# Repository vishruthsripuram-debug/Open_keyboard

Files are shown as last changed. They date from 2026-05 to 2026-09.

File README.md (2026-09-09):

# Nano pad
A 4 key macro pad that you can program actions to.
Screenshot 2026-05-01 at 12 41 59 pm

## Design
My inspiration for this macro pad was the printed pad by prota design but i wanted to make something smaller and cheaper than both of their offering the printed pad and glyff. The printed pad being $68 seemed quite unreasonable to me seeing as it was only a screen a few key swicthes and a microcontroller.

I wanted the project to be simple and easily accessible and customisable by many people so all of the PCB design files are included in the rep for download and printing from a pcb service. The case is 3d printable in any colour you like and customisable to include a knob or other features as step and other cad files are included. The model has also been published on makerworld for the ease of use with Bambulab printers. The whole idea is to hace a simple good looking macro pad that anyone can own for under $15 USD, for 25 USD you can own 5 macro pads.

## BOM

## Bill of Materials — Macro Pad

| Item # | Designator | Qty | Manufacturer | Mfg Part # | Description / Value | Package/Footprint | Type | Notes |
|---|---|---|---|---|---|---|---|---|
| 1 | SW1, SW2, SW3, SW4 | 4 | Cherry (preferred) | MX1A-G1NW | MX Brown, tactile, PCB mount, 5-pin | SW_Cherry_MX_1.00u_PCB | THT | If out of stock, substitute OK: any 5-pin PCB-mount MX-compatible Brown tactile switch (e.g. Gateron KS-3 Brown, Kailh Box/MX Brown, Outemu Brown) — all fit this footprint |
| 2 | U1 | 1 | DFRobot | DFR0648 | Fermion 0.91" 128x32 SSD1306 OLED, I2C, top-mounted pin header (OLED-B) | Module, pin header, THT | THT | Pins are on the short top edge, NOT the long side — confirm this exact pinout before substituting |
| 3 | U2 | 1 | Seeed Studio | 101991470 | XIAO ESP32-C6 module (Tape and Reel, SMD variant) | SMD castellated module | SMD | — |

## Software
software

## Collaboration
In collaboration with PCBWay


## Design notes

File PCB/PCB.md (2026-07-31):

All of the PCB files are located in this folder

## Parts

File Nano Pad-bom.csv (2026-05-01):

Name | Purpose | Quantity | Total Cost (USD) | Link | Distributor
seeed studio esp32 c6 | micrcontroller | 1 | 5.00 | https://www.digikey.com/en/products/detail/seeed-technology-co-ltd/113991254/24613066 | digikey
Key switches | for the macropad buttons | 1 | 2.00 | https://keychron.com.au/products/cherry-switch-set | keychron/aliexpress
Screen | to display features | 1 | 2.50 | https://aliexpress.com | aliexpress
PCB | To connect all components | 1 | 1.00 | https://cart.jlcpcb.com/shopcart/cart | JLC PCB

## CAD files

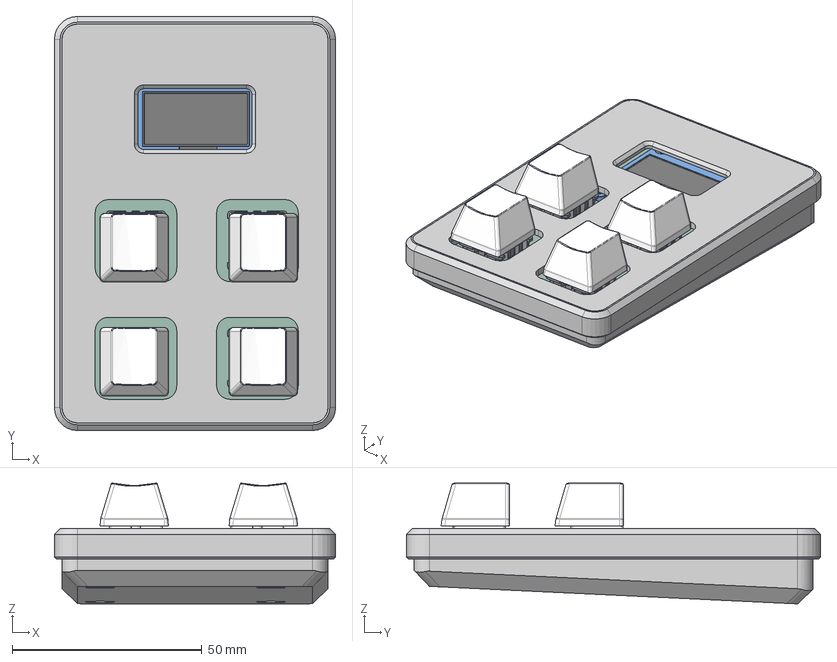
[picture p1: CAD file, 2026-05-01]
3D models/Macro pad.step
74.0 x 109.0 x 31.8 mm
Base
Adafruit_SSD1306
Macro pad_PCB
Bottom x 4
Pulsador x 4
Top x 4
Pieza5^Cherry MX x 4
Pin1 x 4
Pin2 x 4
Led 3mm_trans x 4
Lid
BOSS-EXTRUDE14_8_
BOSS-EXTRUDE7_4_
BOSS-EXTRUDE7_3_
BOSS-EXTRUDE14_4_
BOSS-EXTRUDE14_2_
BOSS-EXTRUDE14_11_
BOSS-EXTRUDE7_7_
BOSS-EXTRUDE14_9_
BOSS-EXTRUDE14_3_
BOSS-EXTRUDE14_7_
MIRROR2
BOSS-EXTRUDE14_5_
BOSS-EXTRUDE14_12_
BOSS-EXTRUDE7_8_
BOSS-EXTRUDE7_1_
BOSS-EXTRUDE14_10_
BOSS-EXTRUDE7_9_
BOSS-EXTRUDE14_6_
BOSS-EXTRUDE14_1_
BOSS-EXTRUDE7_6_
BOSS-EXTRUDE7_2_
CUT-EXTRUDE5
BOSS-EXTRUDE7_5_
U.FL Connector v1
Button (1) x 2
Shield
MX Öá±ê×¼¼üÃ±_ _¨¹_¡À__¡§1__¨¤ x 4

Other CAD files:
3D models/Macro pad.3mf
3D models/Macro pad.f3z

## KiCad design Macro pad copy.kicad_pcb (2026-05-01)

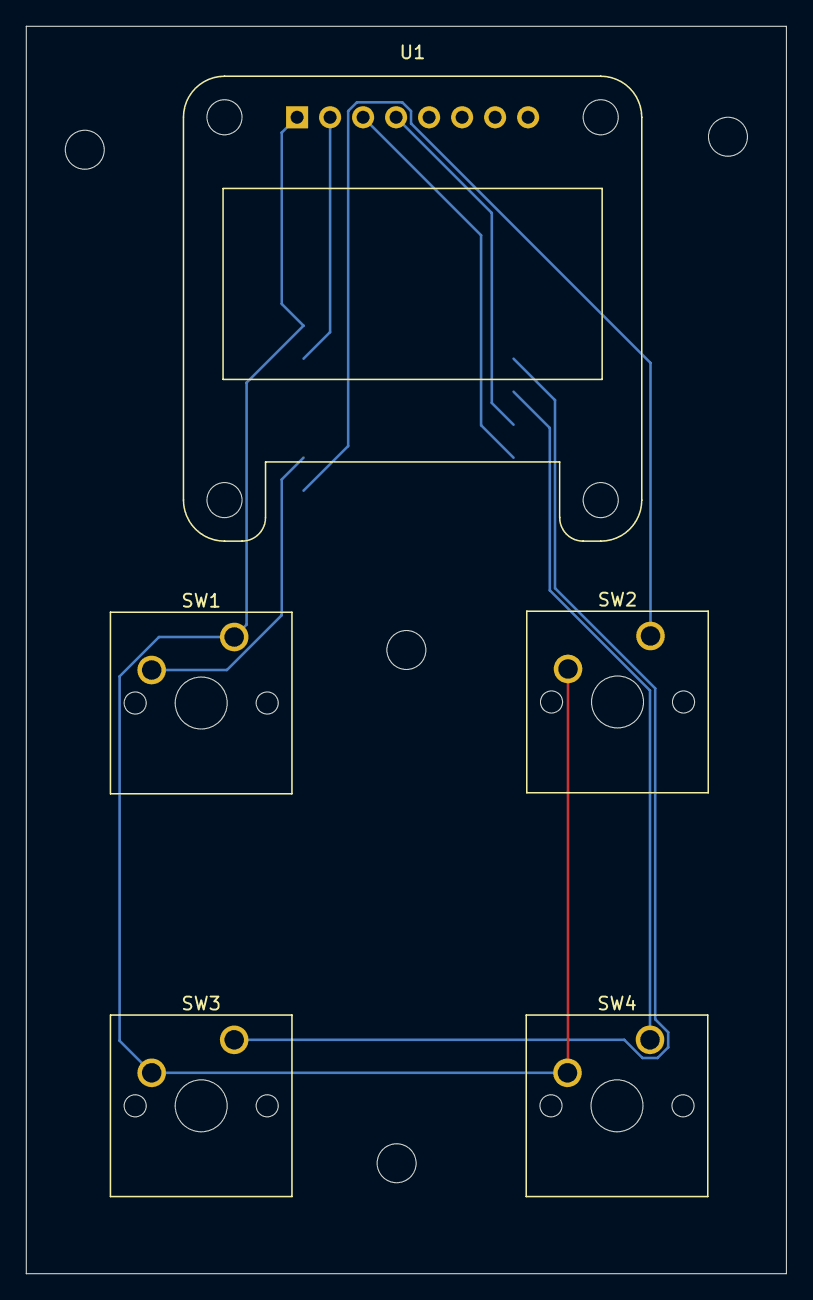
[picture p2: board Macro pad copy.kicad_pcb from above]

Board: 2 copper layers, 58.5 x 96.0 mm, 6 parts (1 on the bottom side), 8 nets.

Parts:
SW1, SW2, SW3, SW4: SW_Push; SW_Cherry_MX_1.00u_PCB
U1: ER_OLEDM0.91_1x-I2C; Adafruit_SSD1306
U2: MOUDLE-SEEEDUINO-XIAO; XIAO-ESP32-C6-SMD

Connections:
GND: SW1.1, SW2.2, SW3.2, SW4.2, U1.1 (GND), U2.13 (GND)
unnamed: U1.3 (SCL), U2.6 (PA9_A5_D5_SCL)
unnamed: U1.4 (SDA), U2.5 (PA8_A4_D4_SDA)
unnamed: U1.2 (VCC), U2.12 (3V3)
unnamed: SW1.2, U2.9 (PA7_A8_D8_SCK)
unnamed: SW3.1, U2.3 (PA10_A2_D2)
unnamed: SW4.1, U2.4 (PA11_A3_D3)
unnamed: SW2.1, U2.8 (PB09_A7_D7_RX)

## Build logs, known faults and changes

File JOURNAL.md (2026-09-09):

# 5/1/2026 - Designing PCB

**Time spent:** 5.5h

PCB Design



Schematic

I first started with the schematic, for the schematic i decided to follow the Hackpad guide for the switches and the microcontroller but i decided to add my own twist which was the screen. The screen is an adafruit oled display with screw mounting holes for mounting onto the PCB. The schematic also included the seeeduino board used in the hackpad guide.

I had to do the schematic twice because for the first time i didnt properly connect the parts together in the schema so in the PCB editor when i was routing the routes weren't connecting.

For the schematic my main concern was with the Tracing. finding the most optimal paths for the lines was incredibly difficult and arranging the traces. The traces were particularly hard to arrange with the ground line but i figured out that i could instead use the same extended ground line essentially piggy backing off of the other ground pins.



*The wiring of the schematic was a bit messy because of the layout i used*

PCB editor

Within the PCB editor is where i designed the main PCB, it took me a while to figure out that i had to assign footprints to the components in the schematic editor. I then placed all of the components in a desirable layout for the macro pad making it simple and good looking fr the macropad. I realised the gap was quite significant when designing in fusion however I was able to fix this after the fact.

The routing was the most significantly difficult part in my opinion it took me multiple attempts and a bunch of tries after deleting multiple routes because the others didn't fit and then, i finally found a layout that would work, but in the DRC it said that my components weren't connected so i check back and realised all my routes were in the top layer of my PCB and not connecting to the microcontroller on the bottom layer, so i had to undo everything and restart from the bottom layer. I realised i could interconnect the ground pins to simplify the layout and reduce the overall wires going to the microcontroller.



After a while of trial and error i eventually figured it out and was able to properly route everything and the DRC showed a fully working PCB, i also learnt about the layers which instructed me to build the pcb frame on the edge cuts layer.

---

# 5/1/2026 - CAD design

**Time spent:** 3.5h

I designed the PCB case in Fusion 360

My inspiration for this macro pad was the printed pad by Prota design but i wanted to make something smaller and cheaper than both of their offering the printed pad and glyff.

Step 1

I first exported the step file of my PC into fusion by exporting out of KIcad, here i encountered some errors explained in the previous journal entry where my routing want correct and the DRC wasnt approving my project to be exported due to those errors. Eventually i figured it out and exported it as a step file into fusion 360 where i opened a hybrid design file.

Chellenge
The main challenge with the cad was making it look nice. The Macropad had to be simple and look nice, which was a key requirement. When i designed it it had smooth chamfers and fillets to reflect the design language i was aiming for. The black design refelcts the prota pad well. Further when designing i had to allow ample clearance between the keycaps for them to glide smoothly into the macropad when clicking. 

Finding the correct Cad files for the 



After importing everything into fusion i started the creation of my case for the macro pad PCB. So far i have the PCB laid in the frame with switches laid on top. The switches are cherry mx red switches which provide a satisfying clicking experience had smooth travel. I placed the switches onto the PCB and they fit perfectly.

Whats left

I still have to make a cutout for the microcontroller mounted on the bottom and another cutout for the USB-C cord which provides power and signal to the macro pad.

I also have to design the top shell of the case similar to the Prota design case.

---

# 5/1/2026 - More fusion - Designing lid and adding keycaps

**Time spent:** 3h

In the previous journal entry i said that i would complete the Lid and add the USB charging port and thats what i did.

I designed the lid simply by just creating a sketch on top of the base and creating a 2mm offset for a sturdy but light feel. The holes for the keyswitches have decent clearance for the kycaps to go beneath the top layer for full travel. Cherry mx switches can detect travel amount so i plan to use this in firmware.



---

# 5/1/2026 - I developed the code and editing software for the macropad

**Time spent:** 4.5h

I coded the app for editing the macro pad there are multiple options for holding, double clicking and single pressing, there are also sliders to update these settings.

OLED screen modes

- Laptop battery percentage
- Volume level
- WiFi strength
- CPU temperature
- Custom text
- Uploaded images
- A virtual pet

Web configurator coding

I used CSS for the styles, JS and HTML.

The configurator includes a live preview of the OLED inside the SVG macropad.



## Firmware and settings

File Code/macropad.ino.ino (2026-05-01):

#include <Arduino.h>
#include <Wire.h>
#include <Adafruit_GFX.h>
#include <Adafruit_SSD1306.h>

#define SCREEN_WIDTH 128
#define SCREEN_HEIGHT 64
Adafruit_SSD1306 display(SCREEN_WIDTH, SCREEN_HEIGHT, &Wire, -1);

// Buttons
const int BTN1 = 1;
const int BTN2 = 2;
const int BTN3 = 3;
const int BTN4 = 4;

// Timing
unsigned long holdTime = 500;
unsigned long doubleWindow = 250;

// Pet system
String petType = "blob";
int petHungerRate = 5;
int petSleepTime = 20;
bool petEnabled = false;
unsigned long lastFed = 0;

// Button state struct
struct KeyState {
  bool pressed = false;
  unsigned long pressTime = 0;
  unsigned long lastPress = 0;
};
KeyState keys[4];

// Draw simple pet
void drawPet(bool happy) {
  display.clearDisplay();
  display.setTextColor(SSD1306_WHITE);

  if (petType == "blob") {
    display.fillRect(40, 32, 48, 24, SSD1306_WHITE);
    if (happy) display.fillRect(52, 48, 16, 2, SSD1306_BLACK);
  }

  if (petType == "cat") {
    display.fillRect(40, 36, 48, 20, SSD1306_WHITE);
    display.fillRect(42, 28, 10, 10, SSD1306_WHITE);
    display.fillRect(68, 28, 10, 10, SSD1306_WHITE);
    if (happy) display.fillRect(52, 48, 16, 2, SSD1306_BLACK);
  }

  if (petType == "ghost") {
    display.fillRect(40, 28, 48, 28, SSD1306_WHITE);
    if (happy) display.fillRect(52, 48, 16, 2, SSD1306_BLACK);
  }

  display.display();
}

// Handle serial commands
void handleCommand(String cmd) {
  cmd.trim();

  if (cmd.startsWith("SET")) {
    // Example: SET 1 SINGLE CTRL+T
    Serial.println("OK");
  }

  if (cmd.startsWith("SCREEN TEXT")) {
    String text = cmd.substring(cmd.indexOf("\"") + 1, cmd.lastIndexOf("\""));
    display.clearDisplay();
    display.setCursor(0, 32);
    display.setTextSize(1);
    display.print(text);
    display.display();
    Serial.println("OK");
  }

  if (cmd.startsWith("SCREEN IMG")) {
    // Expect 8192 bits
    Serial.println("OK");
  }

  if (cmd.startsWith("SCREEN PET ENABLE")) {
    petEnabled = true;
    drawPet(false);
    Serial.println("OK");
  }

  if (cmd.startsWith("PET FEED")) {
    lastFed = millis();
    drawPet(true);
    delay(600);
    drawPet(false);
    Serial.println("OK");
  }

  if (cmd.startsWith("PET TYPE")) {
    petType = cmd.substring(9);
    drawPet(false);
    Serial.println("OK");
  }

  if (cmd.startsWith("PET HUNGER_RATE")) {
    petHungerRate = cmd.substring(16).toInt();
    Serial.println("OK");
  }

  if (cmd.startsWith("PET SLEEP_TIME")) {
    petSleepTime = cmd.substring(15).toInt();
    Serial.println("OK");
  }
}

void setup() {
  Serial.begin(115200);

  pinMode(BTN1, INPUT_PULLUP);
  pinMode(BTN2, INPUT_PULLUP);
  pinMode(BTN3, INPUT_PULLUP);
  pinMode(BTN4, INPUT_PULLUP);

  display.begin(SSD1306_SWITCHCAPVCC, 0x3C);
  display.clearDisplay();
  display.display();
}

void loop() {
  // Read serial
  if (Serial.available()) {
    String cmd = Serial.readStringUntil('\n');
    handleCommand(cmd);
  }

  // Pet idle refresh
  if (petEnabled) {
    if (millis() - lastFed > petHungerRate * 10000) {
      drawPet(false);
    }
  }
}

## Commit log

2026-05-01 PCB files upload
2026-05-23 Update Journal with macropad project details
    Documented progress on custom macropad project, including coding, design, and PCB development.
2026-07-30 Revise JOURNAL.md with project updates
    Updated journal entries with time spent and detailed project progress on PCB design, schematic, and coding for the macropad.
2026-07-31 Rename Nano Pad-bom.csv to BOM.csv
    [BOM.csv]
2026-08-14 Update JOURNAL.md with schematic and CAD challenges
    Added details about schematic tracing challenges and CAD design considerations for the macro pad.
2026-08-28 Adding gerbers and drl files
    [Macro pad-B_Cu.gbr, Macro pad-B_Mask.gbr, Macro pad-B_Paste.gbr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]
2026-09-01 Update distributor for PCB in BOM.csv
    [BOM.csv]
2026-09-09 BOM CSV upload
    [Macro Pad BOM.csv]
2026-09-09 Revise BOM section for macro pad with detailed items
    Updated the Bill of Materials section to include detailed item specifications for the macro pad.
2026-09-09 commit update fiule structure
    [BOM.csv, Macro Pad BOM.csv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]
